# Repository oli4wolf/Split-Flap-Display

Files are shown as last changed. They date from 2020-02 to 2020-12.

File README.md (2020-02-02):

# Flap-Display
This Project is subdivided into different parts

* Initial Codebase of FAI for Toni Prototype
* The plan for a productline
* Project separating into Mechanical Topic, Electronical and Powersupply and the different variants.
** Mechanical Work
** Electronics and Powersupply
** Prototype Toni
** Simplistic Clock
** Complex Modul

# Initial Codebase can be found in this Folder. 
This folder contains the whole documentation with Protocol and manual that could be found and gathered. It's just a collection for historical purpose.
This was the beginning of the project. First it was just a clock from passionate Swiss Federal Railway person for home use. While the split-flap displays
where removed and replaced through digital displays with more flexible options. They created a clock that could be replicated, with the documentation in
French.
This initial work was used to create a gift for the new Boss of the Swiss Federal Railway responsible for person transportation (his name: Toni).
The gift had more capabilities (13x Alphabetic letters). The letter didn't work when the Gift was given.

# The plan for aproductline
A second wave of replacement was delayed and planned for 2019. At the same time an addition for the letters of Toni's variant was planned.
The idea is and was that the electro.-mechanical apprentice with the software apprentice create a second life for the Split-Flap displays.
These were removed and stored. Can be revamped by the electromechanical apprentice and put into a new frame with new electronics and
the more complex modules could be programmed by the software apprentice.
An initial Software can be found in this project. Additional functionality like Network connection or other are in the hand of the apprentices.
## Mechanical Work
(Todo: Topic of Rework anyway solution of split-flaps)
Tonis Gift was a wooden box, which can't be created for a bigger product. We can't create that much wooden box. So the idea is to have a metallic one.
(Todo: The box)
## Electronics and Powersupply
Im not that good in electronics. Therefore i based the rework on the prototype of Toni.
Powersupply stays the same. 
With all clocks we add two buttons (minutes +1, Hour +1).
Complex modules have an additional button (activate messages).

Different buttons have different issues. I added a capacitor to smooven the signal (which helps agains spurious signals).

### Prototype Toni
See initial Codebase

### Simplistic Clock

### Complex modules
See simplistic clock. Addtional i have added a buzzer and an additional button.

## Codebase
### Prototype Toni
See Initial Codebase
### Adding Letters

### Rework the code for simplistic clock

### Rework the code for MKR (Toni Variant)

# Known-Issues
* Somehow i have to have the end/begin of each signal send to a split-flap
* There is no feedback signal if the messages are on or off

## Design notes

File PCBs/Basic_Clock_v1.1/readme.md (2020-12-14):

Version 1.1 Changes
* DIP for the RS485 Maxime microcontroller
* U-Numbers added
* Moved one wire 28v away from pin
* Changed Namings from GND to 0V

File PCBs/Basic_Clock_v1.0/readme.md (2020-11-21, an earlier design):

Version 1.0 Changes
* Placing connector for button like the wiring for electricity.
* Naming for ICSP on PCB to avoid errors.
*

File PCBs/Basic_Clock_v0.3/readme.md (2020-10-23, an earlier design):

Version 0.3 Changes
* C3 Name auf das Board schreiben (allenfalls Werte?)
* LM317 Elemente distanzieren.
* LM317 Platz für Radiator 12.7mm x 12.7mm 
* Kein Rechter Winkel für Verbindungsleitungen
* Stromzufuhrleitung 0.75mm verbreitern
* Leitungen weg von den Sockeln führen
* Quartz näher an den UC (C7) verschieben
* Massebeschriftung auf dem Plan nach unten zeigen lassen

Nur Uhr mit RS485 auf der Platine verbraucht nur 0.046A gegenüber 0.121A mit beiden.
Die Buchse für den Strom ist nur auf 12V und wenige Ampere ausgelegt. Messen ob es mehr braucht.

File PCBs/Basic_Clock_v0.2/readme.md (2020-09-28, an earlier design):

Version 0.2
* Fixes überspannungs LED grösserer Footprint
* Mountingholes
* Reihenfolge Montage zuerst Oscillator, Wiederstand, diode, Socket ,Capacitor, elco, TS202
* Grössere Löcher für die 28V Stromzufuhr.
* RTC weiter entferne und umdrehen.
* Generic Screw Terminal als Anschluss für 28V und GND
* verkleiner der Wiederstand platzierungsgrösse.
* Benennung von R7 war Schweps (zu nah am Rand?).

Checkliste v1.
Hitze des LM317 ist hoch (man verbrennt sich). Allenfalls vergrössern.
Nur Uhr mit RS485 auf der Platine verbraucht nur 0.046A gegenüber 0.121A mit beiden.
Treibt den Kalibrator ohne problem an.

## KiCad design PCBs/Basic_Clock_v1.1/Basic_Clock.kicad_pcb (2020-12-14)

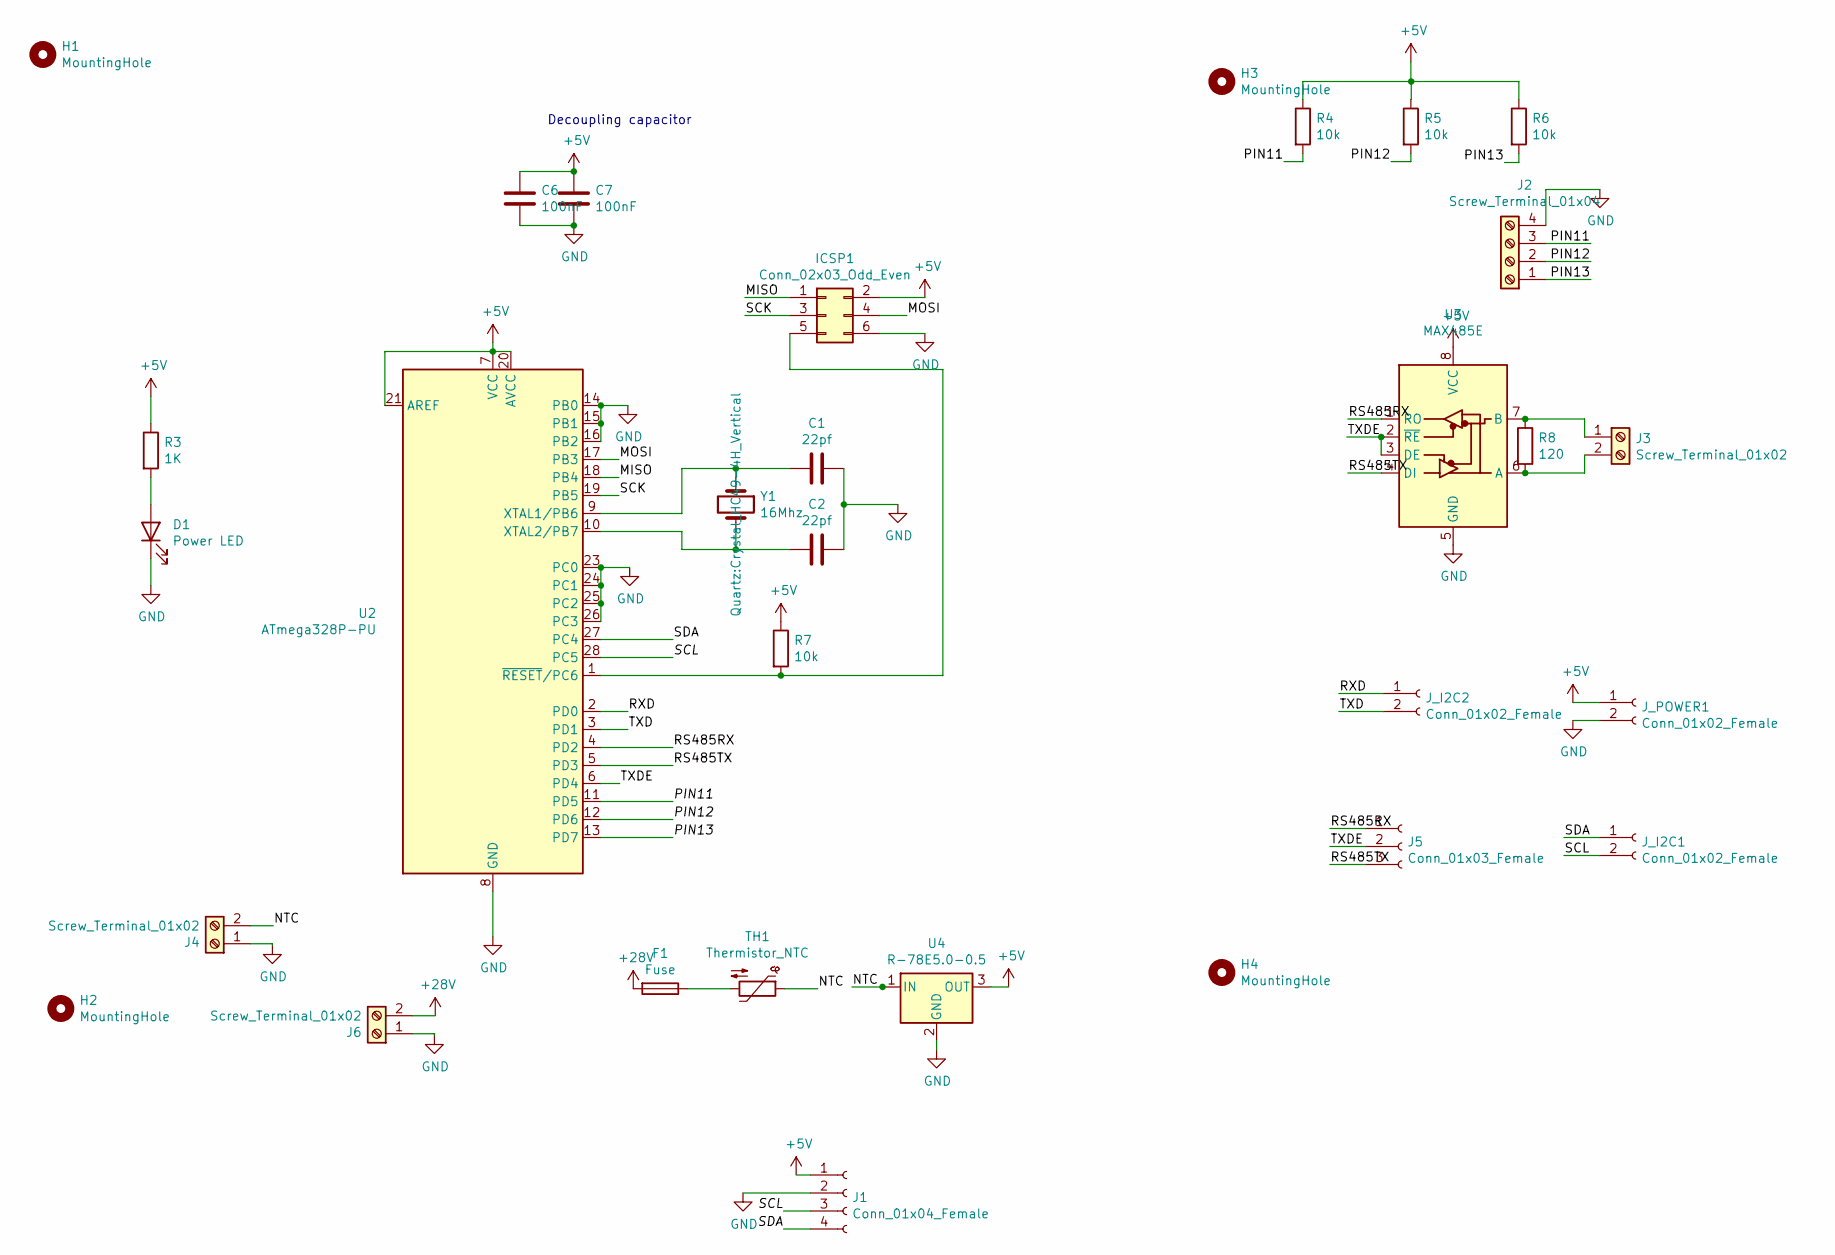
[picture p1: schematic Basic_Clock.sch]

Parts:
C1, C2: 22pf; C_Rect_L7.0mm_W3.5mm_P5.00mm
C6, C7: 100nF; C_Rect_L7.0mm_W3.5mm_P5.00mm
D1: Power LED; LED_D5.0mm_Clear
F1: Fuse; R_Axial_DIN0309_L9.0mm_D3.2mm_P12.70mm_Horizontal
H1, H2, H3, H4: MountingHole; MountingHole_3.2mm_M3_ISO14580
ICSP1: Conn_02x03_Odd_Even; PinSocket_2x03_P2.54mm_Vertical
J1: Conn_01x04_Female; PinSocket_1x04_P2.54mm_Vertical
J2: Screw_Terminal_01x04; TerminalBlock_RND_205-00234_1x04_P5.08mm_Horizontal
J3, J4, J6: Screw_Terminal_01x02; TerminalBlock_RND_205-00232_1x02_P5.08mm_Horizontal
J5: Conn_01x03_Female; PinSocket_1x03_P2.54mm_Vertical
J_I2C1, J_I2C2: Conn_01x02_Female; PinSocket_1x02_P2.54mm_Vertical
J_POWER1: Conn_01x02_Female; PinSocket_1x02_P2.54mm_Vertical
R3: 1K; R_Axial_DIN0309_L9.0mm_D3.2mm_P12.70mm_Horizontal
R4, R5, R6, R7: 10k; R_Axial_DIN0309_L9.0mm_D3.2mm_P12.70mm_Horizontal
R8: 120; R_Axial_DIN0309_L9.0mm_D3.2mm_P12.70mm_Horizontal
TH1: Thermistor_NTC; Crystal_HC49-4H_Vertical
U2: ATmega328P-PU; DIP-28_W7.62mm_Socket
U3: MAX485E; DIP-8_W7.62mm_Socket
U4: R-78E5.0-0.5; Converter_DCDC_RECOM_R-78E-0.5_THT
Y1: 16Mhz; Crystal_HC49-4H_Vertical

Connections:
+5V: C6.1, C7.1, ICSP1.2, J1.1, J_POWER1.1, R3.1, R4.1, R5.1, R6.1, R7.1, U2.7 (VCC), U2.20 (AVCC), U2.21 (AREF), U3.8 (VCC), U4.3 (OUT)
+28V: F1.2, J6.2
/MISO: ICSP1.1, U2.18 (PB4)
/MOSI: ICSP1.4, U2.17 (PB3)
/NTC: J4.2, TH1.1, U4.1 (IN)
/PIN11: J2.3, R4.2, U2.11 (PD5)
/PIN12: J2.2, R5.2, U2.12 (PD6)
/PIN13: J2.1, R6.2, U2.13 (PD7)
/RS485RX: J5.1, U2.4 (PD2), U3.1 (RO)
/RS485TX: J5.3, U2.5 (PD3), U3.4 (DI)
/RXD: J_I2C2.1, U2.2 (PD0)
/SCK: ICSP1.3, U2.19 (PB5)
/SCL: J1.3, J_I2C1.2, U2.28 (PC5)
/SDA: J1.4, J_I2C1.1, U2.27 (PC4)
/TXD: J_I2C2.2, U2.3 (PD1)
/TXDE: J5.2, U2.6 (PD4), U3.2 (~RE), U3.3 (DE)
GND: C1.1, C2.1, C6.2, C7.2, D1.1 (K), ICSP1.6, J1.2, J2.4, J4.1, J6.1, J_POWER1.2, U2.8 (GND), U2.14 (PB0), U2.15 (PB1), U2.16 (PB2), U2.22 (GND), U2.23 (PC0), U2.24 (PC1), U2.25 (PC2), U2.26 (PC3), U3.5 (GND), U4.2 (GND)
unnamed: C1.2, U2.9 (XTAL1/PB6), Y1.1
unnamed: C2.2, U2.10 (XTAL2/PB7), Y1.2
unnamed: D1.2 (A), R3.2
unnamed: F1.1, TH1.2
unnamed: ICSP1.5, R7.2, U2.1 (~RESET~/PC6)
unnamed: J3.1, R8.1, U3.7 (B)
unnamed: J3.2, R8.2, U3.6 (A)

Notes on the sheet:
Decoupling capacitor

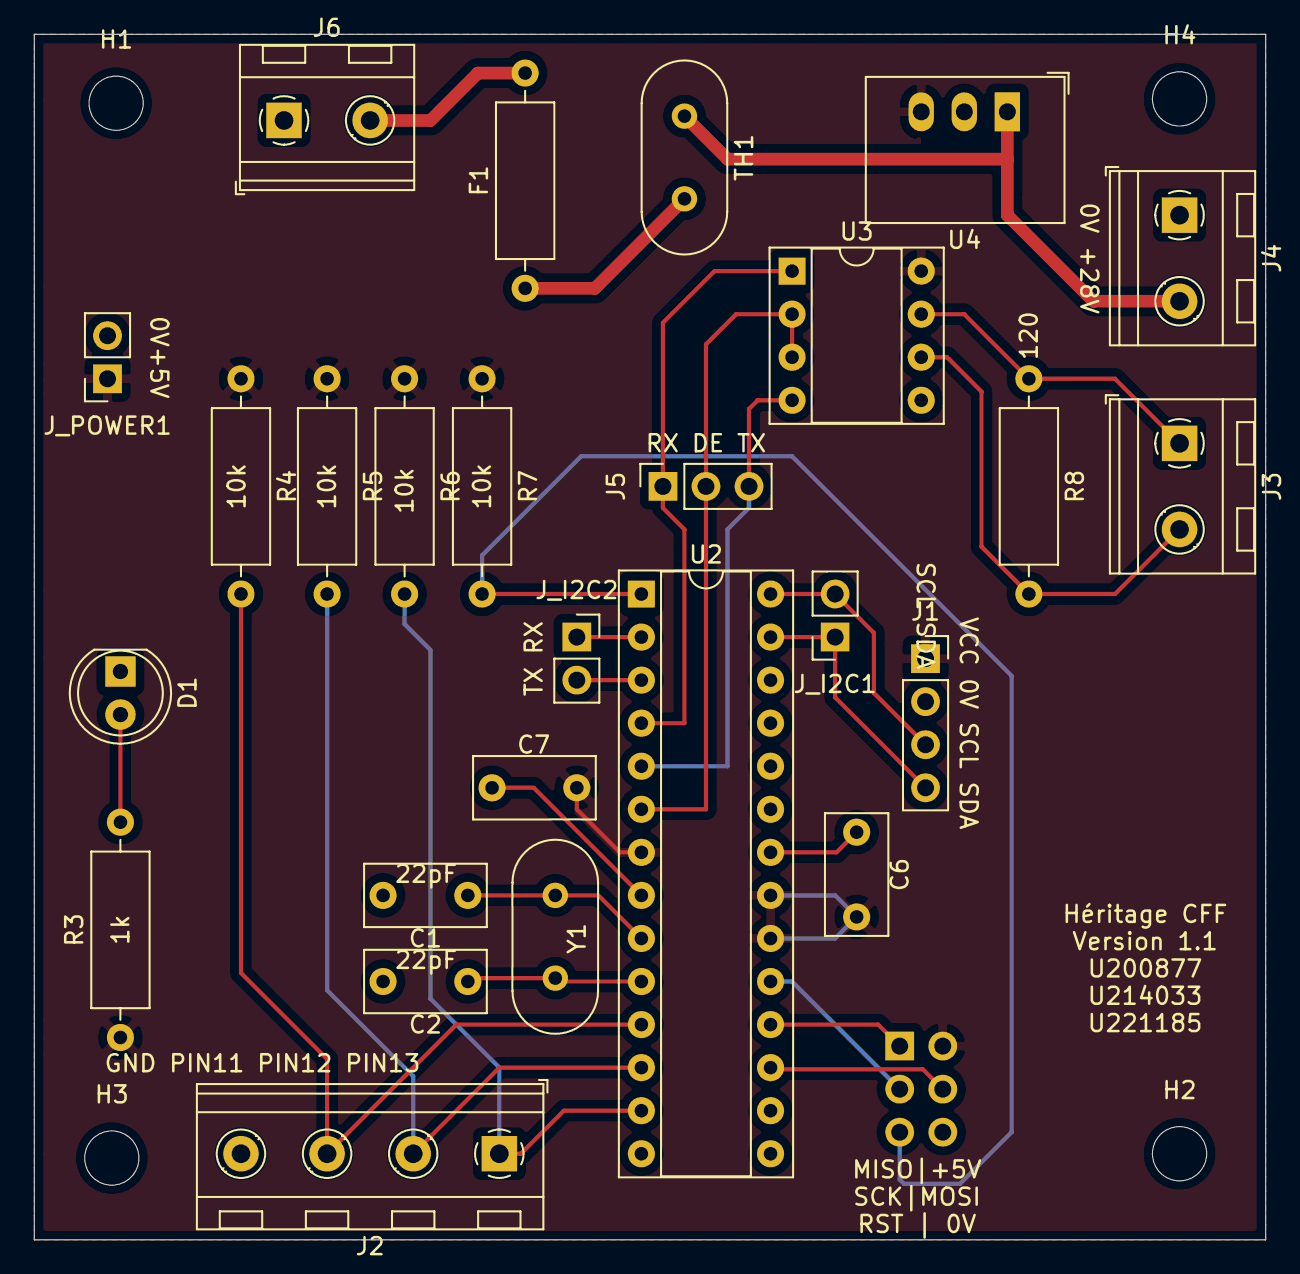
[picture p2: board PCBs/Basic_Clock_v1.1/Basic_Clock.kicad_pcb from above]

Board: 2 copper layers, 72.6 x 71.1 mm, 31 parts (1 on the bottom side), 24 nets.

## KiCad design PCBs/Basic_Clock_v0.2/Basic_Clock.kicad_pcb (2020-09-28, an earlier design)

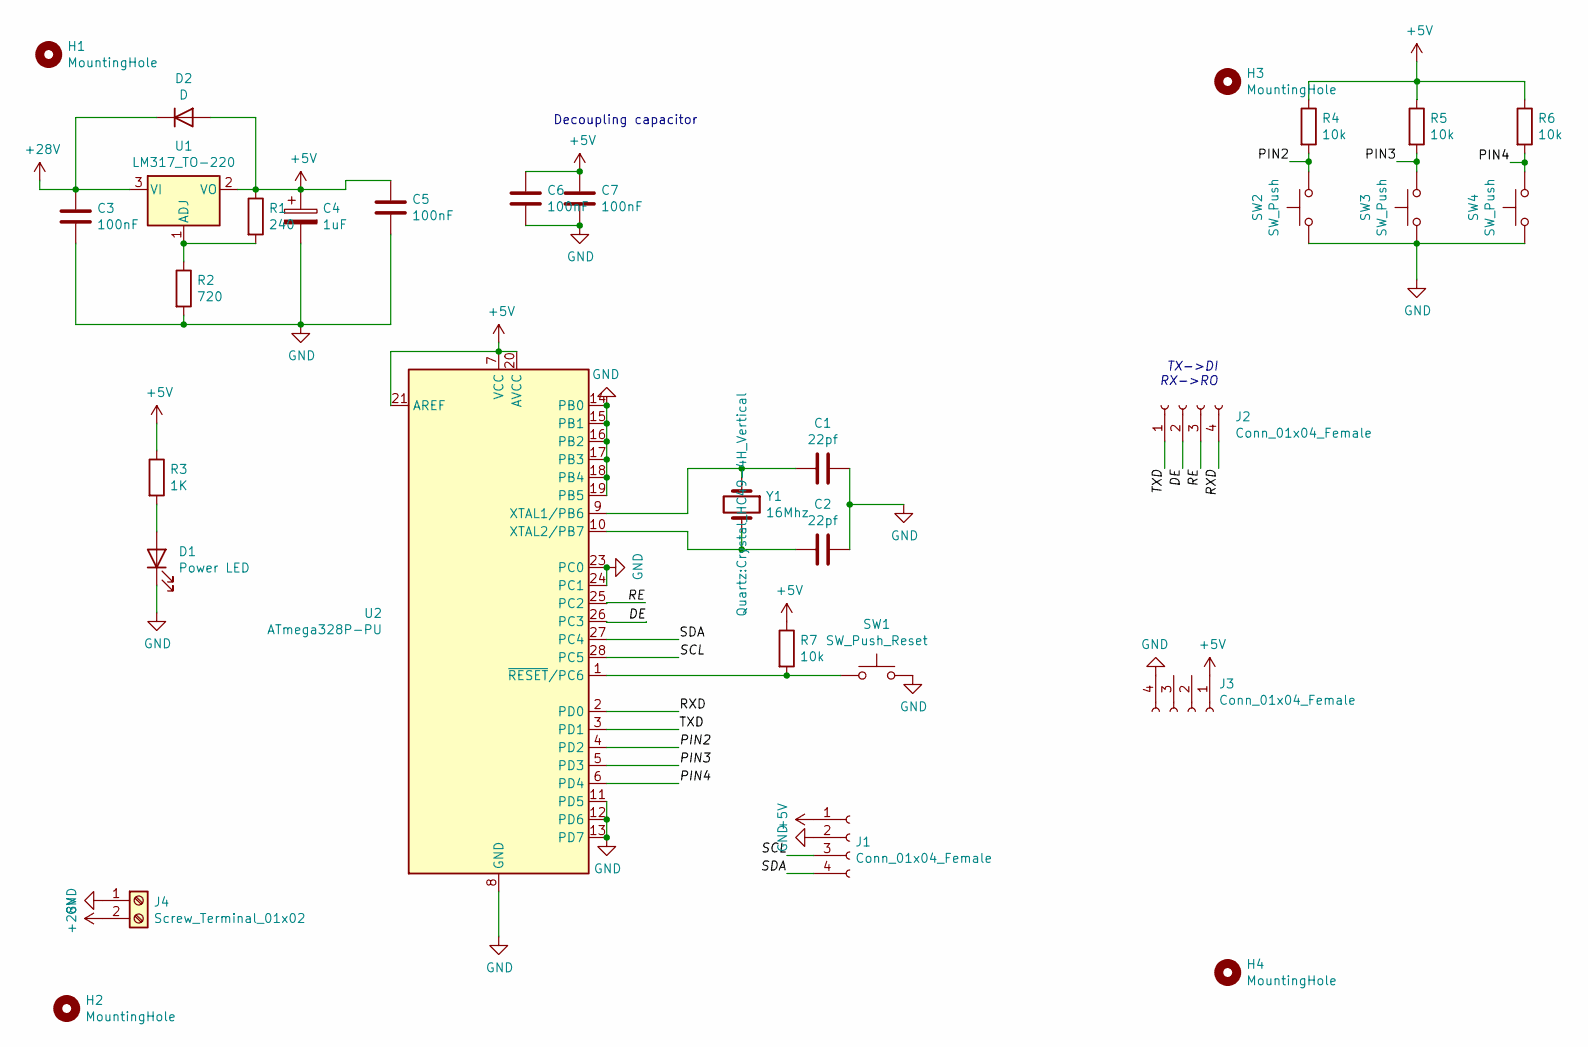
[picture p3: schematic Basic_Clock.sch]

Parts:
C1, C2: 22pf; C_Rect_L7.0mm_W3.5mm_P5.00mm
C3, C5, C6, C7: 100nF; C_Rect_L7.0mm_W3.5mm_P5.00mm
C4: 1uF; CP_Radial_D5.0mm_P2.00mm
D1: Power LED; LED_D5.0mm_Clear
D2: D; D_T-1_P10.16mm_Horizontal
H1, H2, H3, H4: MountingHole; MountingHole_3.2mm_M3_ISO14580
J1, J2, J3: Conn_01x04_Female; PinSocket_1x04_P2.54mm_Vertical
J4: Screw_Terminal_01x02; TerminalBlock_RND_205-00232_1x02_P5.08mm_Horizontal
R1: 240; R_Axial_DIN0309_L9.0mm_D3.2mm_P12.70mm_Horizontal
R2: 720; R_Axial_DIN0309_L9.0mm_D3.2mm_P12.70mm_Horizontal
R3: 1K; R_Axial_DIN0309_L9.0mm_D3.2mm_P12.70mm_Horizontal
R4, R5, R6, R7: 10k; R_Axial_DIN0309_L9.0mm_D3.2mm_P12.70mm_Horizontal
SW1: SW_Push_Reset; SW_PUSH_6mm_H5mm
SW2, SW3, SW4: SW_Push; SW_PUSH_6mm_H5mm
U1: LM317_TO-220; TO-220-3_Vertical
U2: ATmega328P-PU; DIP-28_W7.62mm_Socket
Y1: 16Mhz; Crystal_HC49-4H_Vertical

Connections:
+5V: C4.1, C5.1, C6.1, C7.1, D2.2 (A), J1.1, J3.1, R1.1, R3.1, R4.1, R5.1, R6.1, R7.1, U1.2 (VO), U2.7 (VCC), U2.20 (AVCC), U2.21 (AREF)
+28V: C3.1, D2.1 (K), J4.2, U1.3 (VI)
/DE: J2.2, U2.26 (PC3)
/PIN2: R4.2, SW2.2, U2.4 (PD2)
/PIN3: R5.2, SW3.2, U2.5 (PD3)
/PIN4: R6.2, SW4.2, U2.6 (PD4)
/RE: J2.3, U2.25 (PC2)
/RXD: J2.4, U2.2 (PD0)
/SCL: J1.3, U2.28 (PC5)
/SDA: J1.4, U2.27 (PC4)
/TXD: J2.1, U2.3 (PD1)
GND: C1.1, C2.1, C3.2, C4.2, C5.2, C6.2, C7.2, D1.1 (K), J1.2, J3.4, J4.1, R2.2, SW1.2, SW2.1, SW3.1, SW4.1, U2.8 (GND), U2.11 (PD5), U2.12 (PD6), U2.13 (PD7), U2.14 (PB0), U2.15 (PB1), U2.16 (PB2), U2.17 (PB3), U2.18 (PB4), U2.19 (PB5), U2.22 (GND), U2.23 (PC0), U2.24 (PC1)
unnamed: C1.2, U2.9 (XTAL1/PB6), Y1.1
unnamed: C2.2, U2.10 (XTAL2/PB7), Y1.2
unnamed: D1.2 (A), R3.2
unnamed: R1.2, R2.1, U1.1 (ADJ)
unnamed: R7.2, SW1.1, U2.1 (~RESET~/PC6)

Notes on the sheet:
Decoupling capacitor
TX->DI RX->RO

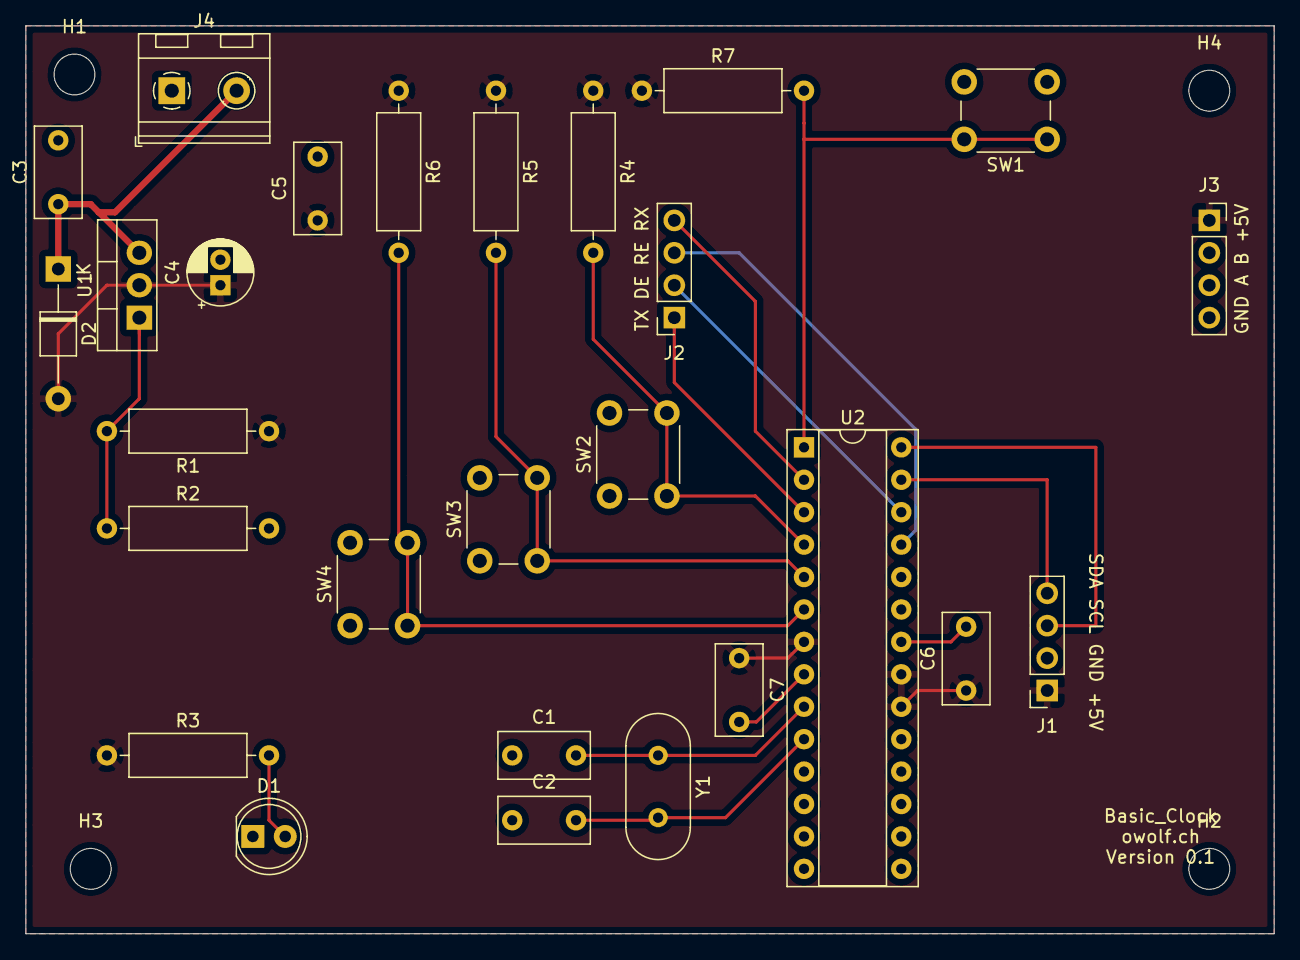
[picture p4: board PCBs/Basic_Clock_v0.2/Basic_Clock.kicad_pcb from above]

Board: 2 copper layers, 97.8 x 71.1 mm, 31 parts (0 on the bottom side), 17 nets.

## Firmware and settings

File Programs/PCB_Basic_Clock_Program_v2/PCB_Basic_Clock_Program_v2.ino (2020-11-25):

/*
  Second Version of the PCB Basic Clock Program.
  Debounce logic https://www.arduino.cc/en/Tutorial/BuiltInExamples/Debounce
   DS3231 library https://tronixstuff.com/2014/12/01/tutorial-using-ds1307-and-ds3231-real-time-clock-modules-with-arduino/
   Used over the Wire library. This enables me to use it with the Arduino Nano every and MKR 1010 for development.
*/

// Move the position to the default positions for the FIA

#include "Wire.h"
#define DS3231_I2C_ADDRESS 0x68

//*****************
//***** RS485Serial *****
//*****************
#include <SoftwareSerial.h>
SoftwareSerial RS485Serial(2, 3); // RX, TX
#define RS485Control 4  //Pin 6 RS485Serial direction control
#define RS485Transmit    HIGH
#define RS485Receive     LOW

//*****************
//***** Flap Commands *****
//*****************
byte CMD_break[] = {
  0x00
};
byte CMD_SET_POS_CHAR[] = {
  0xFF, 0xC0, 0x00, 0x00 // 255 192 Position Value
};
byte CMD_R_ADR[] = {
  0xFF, 0xDE, 0x28 // 255 222 Value
};
byte CMD_R_TYPE[] = {
  0xFF, 0xDD, 0x7B // 255 221  Value
};

//*************************
// Variables and constants
//*************************
const int PinMinute = 5;    // the number of the pushbutton pin
const int PinHour = 6;    // the number of the pushbutton pin
const int PinSpecial = 7;    // the number of the pushbutton pin

int minuteState;             // the current reading from the input pin
int lastMinuteState = HIGH;   // the previous reading from the input pin
int hourState;             // the current reading from the input pin
int lastHourState = HIGH;   // the previous reading from the input pin
int specialState;             // the current reading from the input pin
int lastSpecialState = HIGH;   // the previous reading from the input pin

// the following variables are unsigned longs because the time, measured in
// milliseconds, will quickly become a bigger number than can be stored in an int.
unsigned long lastDebounceMinute = 0;  // the last time the output pin was toggled
unsigned long lastDebounceHour = 0;  // the last time the output pin was toggled
unsigned long lastDebounceSpecial = 0;  // the last time the output pin was toggled
unsigned long debounceDelay = 50;    // the debounce time; increase if the output flickers

int lastSecondPrint = 0;

// Clock variables
byte second, minute, hour, dayOfWeek, dayOfMonth, month, year;

void setup() {
  // Initialize ds3231 and serial
  Wire.begin();
  RS485Serial.begin(19200);
  pinMode(RS485Control, OUTPUT);
  pinMode(PinMinute, INPUT);
  pinMode(PinHour, INPUT);
  pinMode(PinSpecial, INPUT);
  Serial.begin(9600);
  delay(1000);

// Initialize clock at start
  readDS3231time(&second, &minute, &hour, &dayOfWeek, &dayOfMonth, &month,
                 &year);
    writeHour(hour);
    writeMinute(minute);
}

void loop() {
  readDS3231time(&second, &minute, &hour, &dayOfWeek, &dayOfMonth, &month,
                 &year);

  if (lastSecondPrint != second) {
    Serial.print(hour);
    Serial.print(":");
    Serial.print(minute);
    Serial.print(":");
    Serial.println(second);
    lastSecondPrint = second;
  }

  if (second == 5) {
    writeHour(hour);
    writeMinute(minute);
    delay(1000);
  }

  // Debounce logic for Minute
  int reading = digitalRead(PinMinute);
  if (reading != lastMinuteState) {
    lastDebounceMinute = millis();
  }

  if ((millis() - lastDebounceMinute) > debounceDelay) {

    if (reading != minuteState) {
      minuteState = reading;
        Serial.println("Last debounce diff Minute");
        Serial.println(millis() - lastDebounceMinute);

      if (minuteState == LOW) {
        minute = (minute + 1) % 60;
        setDS3231time(0, minute, hour, dayOfWeek, dayOfMonth, month, year);
        writeMinute(minute);
      }
    }
  }
  lastMinuteState = reading;

  // Debounce logic for Hour
  reading = digitalRead(PinHour);
  if (reading != lastHourState) {
    lastDebounceHour = millis();
  }
  if ((millis() - lastDebounceHour) > debounceDelay) {
    if (reading != hourState) {
      hourState = reading;

      if (hourState == LOW) {
        hour = (hour + 1) % 24;
        setDS3231time(0, minute, hour, dayOfWeek, dayOfMonth, month, year);
        writeHour(hour);
      }
    }
  }
  lastHourState = reading;

  // Debounce logic for Special
  reading = digitalRead(PinSpecial);
  if (reading != lastSpecialState) {
    lastDebounceSpecial = millis();
  }
  if ((millis() - lastDebounceSpecial) > debounceDelay) {
    if (reading != specialState) {
      specialState = reading;

      // Make the Split Flap turn!
      if (specialState == LOW) {
        minute = (minute - 1);
        if (minute < 0) {
          minute = 59;
        }
        hour = (hour - 1);
        if (hour < 0) {
          hour = 23;
        }
        writeHour(hour);
        writeMinute(minute);
        delay(2000);
        readDS3231time(&second, &minute, &hour, &dayOfWeek, &dayOfMonth, &month,
                 &year);
        writeHour(hour);
        writeMinute(minute);
      }
    }
  }
  lastSpecialState = reading;
}

void writeMinute(byte value) {
        writePosition(2, ((value+30) % 61));
}

void writeHour(byte value) {
        writePosition(1, hour % 24);
}

/** Helper for RS485Serial **/
void writePosition(byte addr, byte value) {
  gen_break();
  CMD_SET_POS_CHAR[2] = addr;
  CMD_SET_POS_CHAR[3] = value;
  RS485Serial.write(CMD_SET_POS_CHAR, 4);
  digitalWrite(RS485Control, RS485Receive);
}

int gen_break()
{
  RS485Serial.begin(300);
  digitalWrite(RS485Control, RS485Transmit);
  RS485Serial.write(CMD_break, 1);
  delay(10);               // wait
  RS485Serial.begin(19200);
  delay(2);
}

/** Helper methods **/
// Convert normal decimal numbers to binary coded decimal
byte decToBcd(byte val)
{
  return ( (val / 10 * 16) + (val % 10) );
}
// Convert binary coded decimal to normal decimal numbers
byte bcdToDec(byte val)
{
  return ( (val / 16 * 10) + (val % 16) );
}

/** DS3231 Helper**/
void setDS3231time(byte second, byte minute, byte hour, byte dayOfWeek, byte
                   dayOfMonth, byte month, byte year)
{
  // sets time and date data to DS3231
  Wire.beginTransmission(DS3231_I2C_ADDRESS);
  Wire.write(0); // set next input to start at the seconds register
  Wire.write(decToBcd(second)); // set seconds
  Wire.write(decToBcd(minute)); // set minutes
  Wire.write(decToBcd(hour)); // set hours
  Wire.write(decToBcd(dayOfWeek)); // set day of week (1=Sunday, 7=Saturday)
  Wire.write(decToBcd(dayOfMonth)); // set date (1 to 31)
  Wire.write(decToBcd(month)); // set month
  Wire.write(decToBcd(year)); // set year (0 to 99)
  Wire.endTransmission();
}

void readDS3231time(byte *second,
                    byte *minute,
                    byte *hour,
                    byte *dayOfWeek,
                    byte *dayOfMonth,
                    byte *month,
                    byte *year)
{
  Wire.beginTransmission(DS3231_I2C_ADDRESS);
  Wire.write(0); // set DS3231 register pointer to 00h
  Wire.endTransmission();
  Wire.requestFrom(DS3231_I2C_ADDRESS, 7);
  // request seven bytes of data from DS3231 starting from register 00h
  *second = bcdToDec(Wire.read() & 0x7f);
  *minute = bcdToDec(Wire.read());
  *hour = bcdToDec(Wire.read() & 0x3f);
  *dayOfWeek = bcdToDec(Wire.read());
  *dayOfMonth = bcdToDec(Wire.read());
  *month = bcdToDec(Wire.read());
  *year = bcdToDec(Wire.read());
}

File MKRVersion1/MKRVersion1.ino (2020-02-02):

/*
   http://www.arduino.cc/en/Tutorial/Button
   Debounce Example public domain http://www.arduino.cc/en/Tutorial/Debounce
   DS3231 library https://tronixstuff.com/2014/12/01/tutorial-using-ds1307-and-ds3231-real-time-clock-modules-with-arduino/
   Used over the Wire library. This enables me to use it with the Arduino Nano every and MKR 1010.
*/

// ToDo Known-Bug RS485 break signal has an end and start. Somehow this seems to be required?
// ToDo The position of the message and minutes at home seem not to be correct (have to be checked at tonis place)

#include "Wire.h"
#include <ArduinoRS485.h>
#include "mappingTable.h"
#include "messageTable.h"
#define DS3231_I2C_ADDRESS 0x68

byte CMD_break[] = {
  0x00
};
//Minute at position 1
byte CMD_SET_POS_MINUTE[] = {
  0xFF, 0xC0, 0x01, 0x00  //Addr 0x01 for Tonis FAI
};
byte CMD_SET_POS_HOUR[] = {
  0xFF, 0xC0, 0x00, 0x00 //Addr 0x00 for Tonis FAI
};
byte CMD_SET_POS_CHAR[] = {
  0xFF, 0xC0, 0x00, 0x00
};

// constants won't change. They're used here to set pin numbers:
const int buttonPinMinute = 0;     // the number of the pushbutton pin
const int buttonPinHour = 1;     // the number of the pushbutton pin
const int buttonPinMessageEnabled = 7;     // the number of the PTSD pin

// the following variables are unsigned longs because the time, measured in
// milliseconds, will quickly become a bigger number than can be stored in an int.
unsigned long lastDebounceTimeMinute = 0;  // the last time the output pin was toggled
unsigned long lastDebounceTimeHour = 0;  // the last time the output pin was toggled
unsigned long lastDebounceMessageEnabled = 0;  // the last time the output pin was toggled

// variables will change:
int lastButtonStateMinute = 1;   // variable to memorize the last state to recognize if a state change happend
int lastButtonStateHour = 1;        // variable to memorize the last state to recognize if a state change happend
int lastButtonStateMessageEnabled = 1;        // variable to memorize the last state to recognize if a state change happend
int displayTextMemory = HIGH;
int messageEnabled = LOW;
int messageEnabledSerial = LOW;

// shorten the interrupt
int incrementMinute = LOW;
int incrementHour = LOW;

// Clock variables
byte second, minute, hour, dayOfWeek, dayOfMonth, month, year;

void setup() {
  // initialize the pushbutton pin as an interrupt:
  attachInterrupt(digitalPinToInterrupt(buttonPinMessageEnabled), interruptDebounceMessageEnable, CHANGE);
  attachInterrupt(digitalPinToInterrupt(buttonPinMinute), interruptDebounceMinute, CHANGE);
  attachInterrupt(digitalPinToInterrupt(buttonPinHour), interruptDebounceHour, CHANGE);

  // Initialize ds3231 and serial
  Wire.begin();
  Serial.begin(9600);
  RS485.begin(19200);

  // set the initial time here (we don't have a display anymore so have to set it once at the beginning)
  // DS3231 seconds, minutes, hours, day, date, month, year
  //setDS3231time(00, 22, 20, 6, 29, 1, 20);
  delay(1000);
}

void loop() {
  // Show clock Time at 05 Seconds of the minute//
  readDS3231time(&second, &minute, &hour, &dayOfWeek, &dayOfMonth, &month,
                 &year);
  if (second == 5 && displayTextMemory == HIGH) {
    displayTextMemory = LOW;
    writeMinute(minute);
    writeHour(hour);
    displayTime();
    //If it was shown once then it is enough
  } else if (second != 5 && displayTextMemory == LOW) {
    displayTextMemory = HIGH;
  }

  //Show a message if messageEnabled boolean true and at 0 seconds of the minute
  if (messageEnabled == LOW) {
    if (messageEnabledSerial == LOW) {
      Serial.println("Message deactivated");
      messageEnabledSerial = HIGH;
    }
  } else {
    if (second == 0) {
      messageLoop(minute, hour, dayOfMonth, month); //Day and month for th
    }
    if (messageEnabledSerial == LOW) {
      Serial.println("Message activated");
      messageEnabledSerial = HIGH;
    }
  }

  //Mainloop validates if an interrupt occured and an increment should be done
  //Increment Minute
  if (incrementMinute == HIGH) {
    incrementDS3231Minute();
    Serial.println("Minute");
    incrementMinute = LOW;
  }
  //Increment Hour
  if (incrementHour == HIGH) {
    incrementDS3231Hour();
    Serial.println("Hour");
    incrementHour = LOW;
  }
}

/** Helper for deactivating Message **/
void interruptDebounceMessageEnable() {
  unsigned long interrupt_time = millis();
  // If interrupts come faster than 200ms, assume it's a bounce and ignore
  if (interrupt_time - lastDebounceMessageEnabled > 200)
  {
    if (messageEnabled == HIGH) {
      messageEnabled = LOW;
    } else {
      messageEnabled = HIGH;
    }
    messageEnabledSerial = LOW;
  }
  lastDebounceMessageEnabled = interrupt_time;
}

/** Helper for deactivating Message **/
void interruptDebounceMinute() {
  unsigned long interrupt_time = millis();
  // If interrupts come faster than 200ms, assume it's a bounce and ignore
  if (interrupt_time - lastDebounceTimeMinute > 200)
  {
    incrementMinute = HIGH;
  }
  lastDebounceTimeMinute = interrupt_time;
}

/** Helper for deactivating Message **/
void interruptDebounceHour() {
  unsigned long interrupt_time = millis();
  // If interrupts come faster than 200ms, assume it's a bounce and ignore
  if (interrupt_time - lastDebounceTimeHour > 200)
  {
    incrementHour = HIGH;
  }
  lastDebounceTimeHour = interrupt_time;
}

/** Write Message **/
void messageLoop(byte mm, byte hh, byte dt, byte mo) {
  if (hh > 7 && hh < 23) {
    if (mm == 30 || mm == 0 || hh == 12 || (hh == 10 && mm == 21)) {
      //Random Select entry
      int randMessage = random(15);
      int pointer = 0;
      if (hh == 12) {
        randMessage = 15;
      } else if (hh == 10 && mm == 21) {
        randMessage = 16;
      }

      //Geburtstage ab dem Moment an den Datum anzeigen
      if (hh == 7 || hh == 12 || hh == 19)
        if (dt == 21 && mo == 5) {
          randMessage = 20;
        } else if (dt == 19 && mo == 9) {
          randMessage = 19;
        } else if (dt == 11 && mo == 8) {
          randMessage = 18;
        } else if (dt == 10 && mo == 9) {
          randMessage = 17;
        }

      while (pointer < 33) {
        for (int j = 2; j < 13; ++j) { // Lettres
          //for (int j = 3; j < 14; ++j) { // Lettres at home
          Serial.println("Message to be written");
          writePosition((byte) j, table[randMessage][pointer]);
          pointer++;
        }
        delay(10000);
      }
    }
  }
}

/** Helper for RS485 **/
void writeMinute(byte minute) {
  gen_break();
  RS485.beginTransmission();
  if (minute < 31) {
    CMD_SET_POS_MINUTE[3] = minute;
  } else {
    CMD_SET_POS_MINUTE[3] = minute + 1;
  }
  RS485.write(CMD_SET_POS_MINUTE, 4);
  delay(50);
  RS485.endTransmission();
}

void writeHour(byte hour) {
  gen_break();
  RS485.beginTransmission();
  CMD_SET_POS_HOUR[3] = hour + 8;
  RS485.write(CMD_SET_POS_HOUR, 4);
  delay(50);
  RS485.endTransmission();
}
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

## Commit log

2020-02-02 Initial commit. Initial code from Toni and documentation. Initial code with added messages. New MKR based Version with buttons.
2020-09-14 First draft for the PCB.
    [Basic_Clock.kicad_pcb, Basic_Clock.sch]
2020-09-14 Footprint somehow changed? Fixed and routed the missing with VIAs.
    [Basic_Clock.kicad_pcb, Basic_Clock.sch]
2020-09-15 Revisioned after Feedback from Frank.
    [Basic_Clock.kicad_pcb, Basic_Clock.sch]
2020-09-16 Created Gerber files Updated Components
    [Basic_Clock-B_Cu.gbr, Basic_Clock-B_Mask.gbr, Basic_Clock-B_Paste.gbr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]
2020-09-18 Update production version 0.1
    [Basic_Clock.kicad_pcb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]
2020-09-28 Clock Version 0.2
    [Basic_Clock.kicad_pcb, Basic_Clock.sch]
2020-10-23 New Version 0.3
    [Basic_Clock.kicad_pcb, Basic_Clock.sch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]
2020-10-26 New Testprogram Reorganized Folder
    [Basic_Clock-B_Cu.gbr, Basic_Clock-B_Mask.gbr, Basic_Clock-B_Paste.gbr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]
2020-11-01 Added PCB Version 4 Removed Gerberfiles and drill files
    [Basic_Clock-B_Cu.gbr, Basic_Clock-B_Mask.gbr, Basic_Clock-B_Paste.gbr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]
2020-11-03 PCB Version 0.5
    [Basic_Clock.kicad_pcb, Basic_Clock.sch]
2020-11-03 Move to a folder
    [Basic_Clock-B_Cu.gbr, Basic_Clock-B_Mask.gbr, Basic_Clock-B_Paste.gbr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]
2020-11-04 Update after Feedback.
    [Basic_Clock.kicad_pcb, Basic_Clock.sch]
2020-11-09 PCB 0.6 Fixed inscription Software to test with running.
    [Basic_Clock.kicad_pcb, Basic_Clock.sch]
2020-11-21 PCB Version validated with the Addresses and Positions as configured.
2020-11-21 Final version PCB
    [Basic_Clock.kicad_pcb, Basic_Clock.sch]
2020-11-21 Fixed ICSP Pinout
    [Basic_Clock.kicad_pcb, Basic_Clock.sch]
2020-11-25 PCB latest version.
    [Basic_Clock.kicad_pcb, Basic_Clock.sch]
2020-12-14 KiCad Version 1.1 added NTC and Fuse.
    [Basic_Clock.kicad_pcb, Basic_Clock.sch]
